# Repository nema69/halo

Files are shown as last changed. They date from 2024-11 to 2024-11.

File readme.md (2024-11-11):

# Light Module

## Anforderungen

- Ring mit OD = 50mm und ID = 15mm

- Strom max. 500 mA

- Nennspannung = 24V

## LEDs

#### HONGLITRONIC A2835W6H2-D01-8D2AB5

- LCSC: [C7423447]([A2835W6H2-D01-8D2AB5 HONGLITRONIC(Hongli Zhihui (HONGLITRONIC)) | Optoelectronics - LCSC Electronics](https://www.lcsc.com/product-detail/LED-Indication-Discrete_HONGLITRONIC-Hongli-Zhihui-HONGLITRONIC-A2835W6H2-D01-8D2AB5_C7423447.html))

- Package: SMD2835

- Farbe: Kaltweiß (6500K)

- 

## TODO:

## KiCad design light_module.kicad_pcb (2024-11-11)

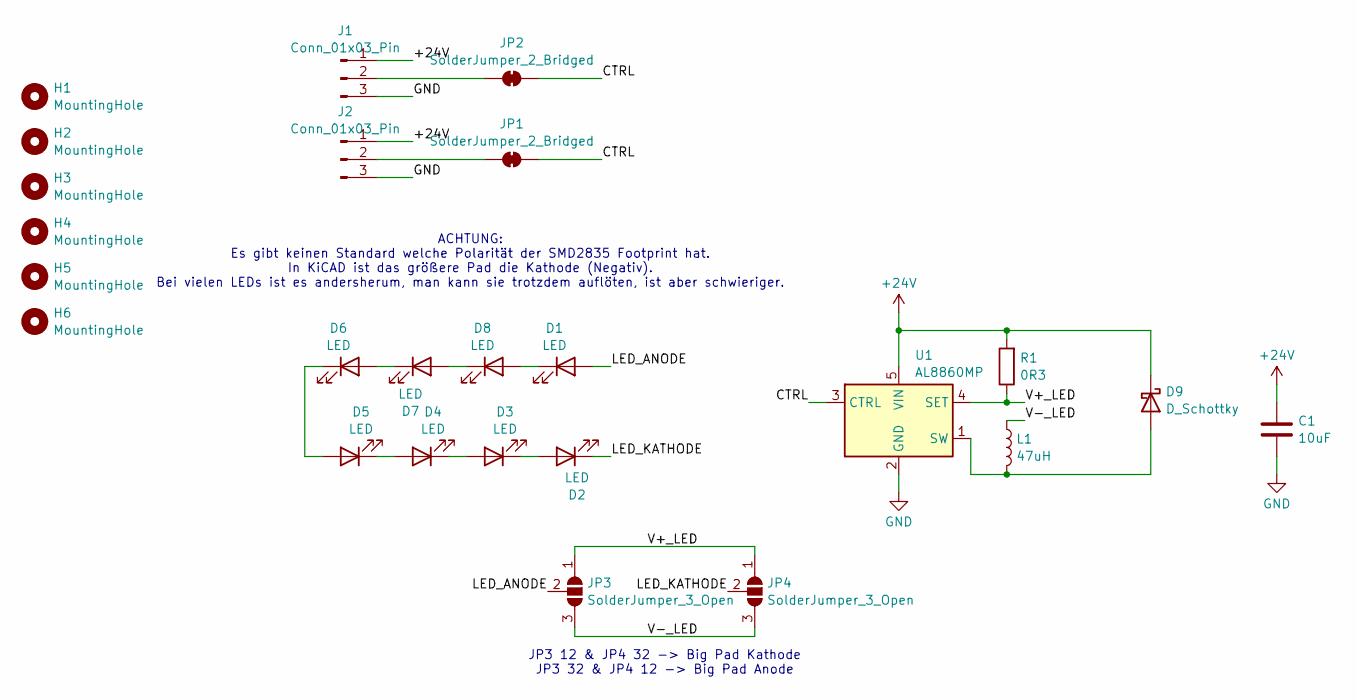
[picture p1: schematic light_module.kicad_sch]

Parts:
C1: 10uF; C_1206_3216Metric_Pad1.33x1.80mm_HandSolder; JLC PN C13585
D1, D2, D3, D4, D5, D6, D7, D8: LED; LED_PLCC_2835_Handsoldering; JLC PN C385302
D9: D_Schottky; D_SOD-123; JLC PN C78545
H1, H2, H3, H4, H5, H6: MountingHole; MountingHole_3.2mm_M3
J1, J2: Conn_01x03_Pin; JST_XH_B3B-XH-A_1x03_P2.50mm_Vertical
JP1, JP2: SolderJumper_2_Bridged; SolderJumper-2_P1.3mm_Bridged_RoundedPad1.0x1.5mm
JP3, JP4: SolderJumper_3_Open; SolderJumper-3_P1.3mm_Open_RoundedPad1.0x1.5mm_NumberLabels
L1: 47uH; L_Changjiang_FNR5020S; JLC PN C5363775
R1: 0R3; R_0805_2012Metric; JLC PN C247157
U1: AL8860MP; TSOT-23-5; JLC PN C155534

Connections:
+24V: C1.1, D9.1 (K), J1.1, J2.1, R1.2, U1.5 (VIN)
/CTRL: JP1.2 (B), JP2.2 (B), U1.3 (CTRL)
/LED_ANODE: D1.2 (A), JP3.2 (C)
/LED_KATHODE: D2.1 (K), JP4.2 (C)
/V+_LED: JP3.1 (A), JP4.1 (A), R1.1, U1.4 (SET)
/V-_LED: JP3.3 (B), JP4.3 (B), L1.1
GND: C1.2, J1.3, J2.3, U1.2 (GND)
unnamed: D1.1 (K), D8.2 (A)
unnamed: D2.2 (A), D3.1 (K)
unnamed: D3.2 (A), D4.1 (K)
unnamed: D4.2 (A), D5.1 (K)
unnamed: D5.2 (A), D6.1 (K)
unnamed: D6.2 (A), D7.1 (K)
unnamed: D7.2 (A), D8.1 (K)
unnamed: D9.2 (A), L1.2, U1.1 (SW)
unnamed: J1.2, JP2.1 (A)
unnamed: J2.2, JP1.1 (A)

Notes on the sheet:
JP3 12 & JP4 32 -> Big Pad Kathode JP3 32 & JP4 12 -> Big Pad Anode
ACHTUNG: Es gibt keinen Standard welche Polarität der SMD2835 Footprint hat. In KiCAD ist das größere Pad die Kathode (Negativ). Bei vielen LEDs ist es andersherum, man kann sie trotzdem auflöten, ist aber schwieriger.

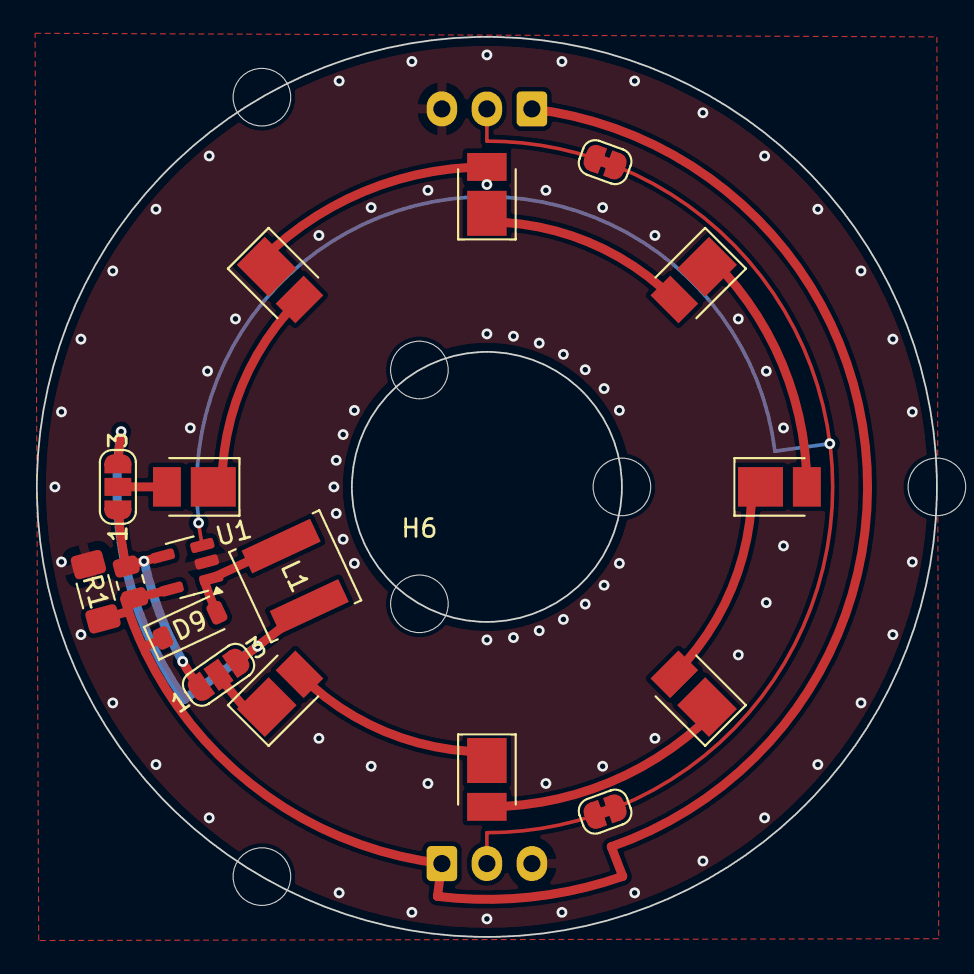
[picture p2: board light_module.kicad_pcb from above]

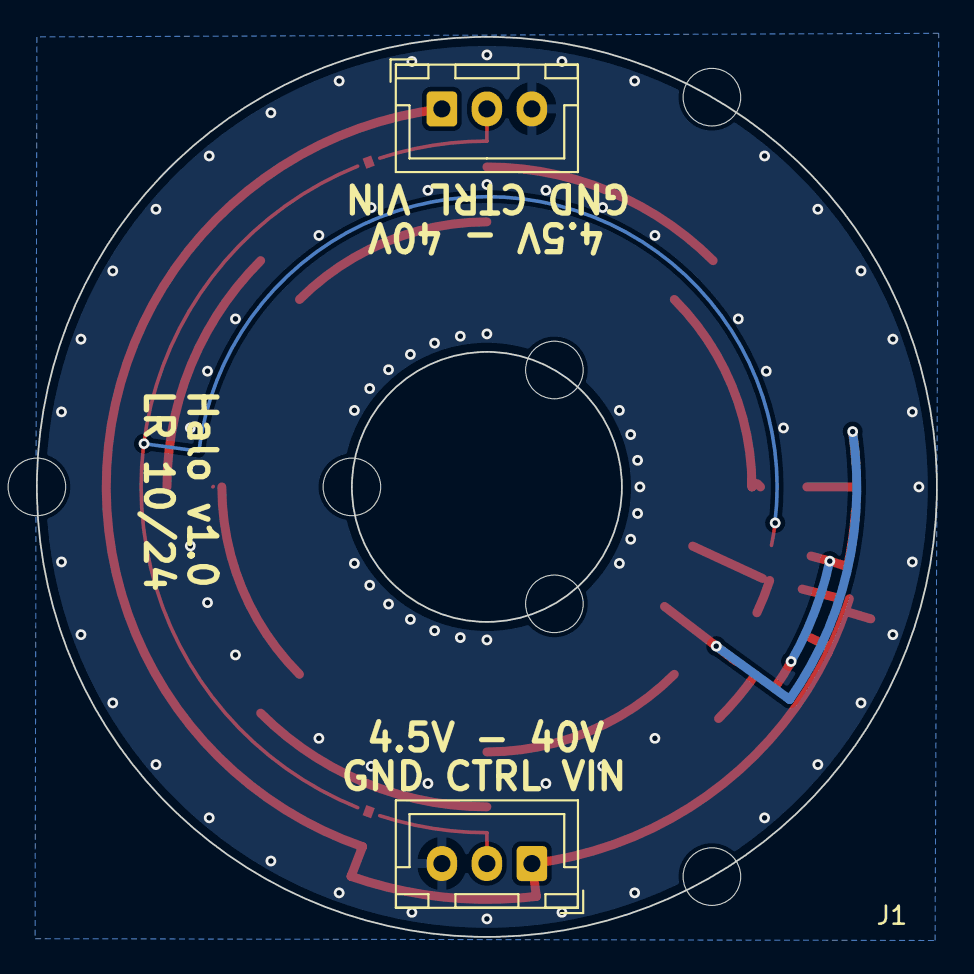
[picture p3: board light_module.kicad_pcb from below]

Board: 2 copper layers, 50.0 x 50.0 mm, 25 parts (2 on the bottom side), 17 nets.
